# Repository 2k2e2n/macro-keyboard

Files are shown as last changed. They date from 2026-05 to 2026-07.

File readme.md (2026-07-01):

# Macro-Keyboard

完全自作マクロキーボード

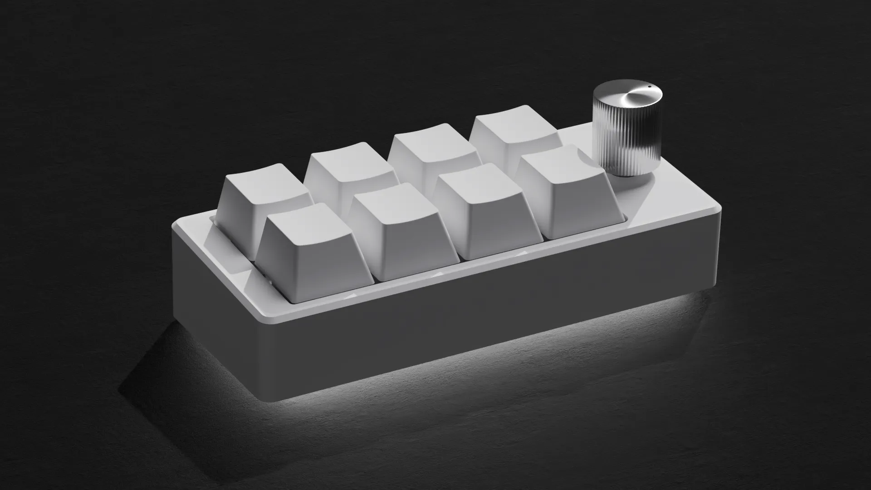
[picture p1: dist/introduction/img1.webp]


---

## Features

* 基板からケースまで完全自作
* webページからキー割り当てを変更可能
* MXcherry hotswapに対応
* ロータリーエンコーダを搭載

## Firmware

[https://2k2e2n.github.io/macro-keyboard/config/](https://2k2e2n.github.io/macro-keyboard/config/)
👆にアクセスして書き換え

もしくは```dist/config/index.html```を開く

## Sales page
作成中

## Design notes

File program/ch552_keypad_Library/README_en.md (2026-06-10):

# ch552_keyPad_Library

Common firmware modules for small keyboards and keypads based on CH552 / ch55xduino.
The folder name for this library is `ch552_keyPad_Library`.
This library includes USB HID composite support (keyboard, mouse, consumer/system, raw HID), watchdog helpers, and NVM keymap handling for programmable devices.

## Usage

Create a folder named `ch552_keyPad_Library` inside Arduino's `libraries` folder, then copy all contents of this repository into it.

## What this library provides

- USB HID composite interface (keyboard, mouse, consumer/system, raw HID channel)
- USB endpoint/setup handling and descriptor constants
- NVM (EEPROM) keymap read/write utilities
- Macro storage and macro index handling in NVM
- Rotary encoder keymap read/write helpers
- CH552 watchdog timer helpers

## Main files

Library files are stored in the `src` directory.

- `USB_hid_composite.c/.h`: HID send API and LED state handling
- `ch_usb_handler.c/.h`: USB endpoint and setup request handling
- `ch_usb_constant.c/.h`: USB descriptors and report constants
- `hid_raw_request.c`: raw HID command handler (for host tools such as WebHID)
- `nvm_keymap.c/.h`: keymap/macro read/write and NVM layout access
- `hardware_config.h`: board/profile dependent memory map and key matrix settings
- `ch552_watchdog.c/.h`: watchdog enable/disable/update helpers
- `hid_keycode.h`: HID keycode definitions

`examples/simple_numPad` contains a simple numpad implementation using this library.

## Build-time configuration

Select one hardware profile in your build flags before including this library:

- `CH552_MACRO_NUMPAD`
- `CH552_MEDIAPAD`

`hardware_config.h` uses these flags to define matrix size, EEPROM map, raw HID ID, and rotary encoder settings.

This library provides a custom CH55x USB handler and therefore requires the CH55xDuino board USB setting that defines `USER_USB_RAM`. If `USER_USB_RAM` is not set, the CH55xDuino core USB handler will conflict with this library and cause duplicate symbol errors.

When adding new hardware support that uses this library, define an appropriate preprocessor macro as needed and update files in this library accordingly. Then specify that macro in `arduino.json` on the hardware implementation side.

Note: if you are not using an NVM-based keymap, as in `examples/simple_numPad`, no build flags are needed.

## Public APIs (high level)

- Watchdog: `wdt_enable()`, `wdt_disable()`, `wdt_update()`
- NVM keymap: `init_nvm_keymap()`, `read_nvm_code()`, `write_nvm_code()`
- Bulk keymap/macro access: `read_keys()`, `write_keys()`, `read_macros()`, `write_macros()`
- USB HID: `usbhid_init()`, `send_key()`, `send_modifiers()`, `kbd_releaseAll()`, `get_hid_ledstate()`

## Raw HID command notes

`hid_raw_request.c` implements command IDs for:

- keymap reset/read/write
- macro read/write
- rotary encoder key read/write
- version query
- bootloader entry

Use this interface from a host configurator to update keymaps and macros stored in NVM.

## License

Copyright (c) 2024 Takeshi Higasa, okiraku-camera.tokyo

MIT License.

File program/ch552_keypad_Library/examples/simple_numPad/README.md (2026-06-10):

# Simple Numeric Keypad Firmware for CH552G

This directory provides a **simple numeric keypad firmware** for the **CH552G** microcontroller. The firmware is intended primarily for **hardware bring-up and USB HID verification**. It enumerates as a **standard USB HID keyboard** and sends key events by scanning 4x5 key-switch matrix. This implementation is based on the `USBHIDKeyboard.c` example included in **CH55xDuino**.

`simple_numPad.ino` uses the **ch552_keyPad_Library** and is provided as one of the examples included with that library. The library supplies the shared CH552 keypad firmware modules, including USB HID handling, watchdog helpers, and keymap/NVM support used by this example.

---

## Features

- Minimal **USB HID keyboard implementation**
- Designed for **CH552G hardware bring-up**
- Simple **Matrix-based numeric keypad**
- Based on the **CH55xDuino USBHIDKeyboard example**
- Easy to build with **Arduino IDE or VS Code**

---

## Build Environment

The firmware can be built using:

- **Arduino IDE 1.8.19**
- **Visual Studio Code** with the *vscode-arduino* extension

Both require **CH55xDuino v0.25**.

### Board Configuration

In the board configuration menu, select:

- **USB Settings:** `USER CODE w/ 148B USB ram`

This option allocates the USB RAM required for HID endpoints.

---

## Hardware

This firmware targets the **ch552_numPad_rev2** hardware. The circuit designs and related files are maintained in a separate repository (**ch552_numPad_rev2**), which is independent of this library repository.

---

## License

Copyright (c) 2023 Takeshi Higasa, okiraku-camera.tokyo
Released under the **MIT License**.

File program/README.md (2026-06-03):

# Macro Keyboard (CH55x)

このディレクトリには、CH55x（CH552/CH554）を使った簡易ショートカットキーボードのファームウェアと設定ツールがあります。

内容:
- `firmware/MacroKeyboard.ino` - Arduino IDE（ch55xduinoコア）用スケッチ
- `configurator/index.html` - ブラウザで編集・ダウンロード・Web Serialでアップロード可能な設定ページ
- `uploader/serial_uploader.py` - シリアル経由で設定を送る簡易Pythonスクリプト

使い方（概要）:
1. Arduino IDEに`ch55xduino`コアをインストールして、`firmware/MacroKeyboard/MacroKeyboard.ino`を開く
2. **ツール > USB Settings** で **「USER CODE w/ 266B USB ram」** を選択（CDC + HID キーボード/マウス用）
3. 指定のピン割り当てを確認してビルド・書き込み
4. 設定を変更するには、`configurator/index.html`を開いてキーを編集後「Download」または「Connect & Upload」を使う
   - Web Serialが使えない場合はダウンロードした`keymap.txt`を`uploader/serial_uploader.py`で送信

設定フォーマット:
- デバイスは起動時に`P3.0`（debug）を押しながら電源投入/リセットすると、115200bpsでシリアルを開いて8個のトークンをカンマ区切りで受け取ります。
- 例: `a,CTRL+B,ENTER,MW_UP,WIN, ,LEFT,SPACE`
- トークンは単一文字、修飾キーとの組み合わせ（`CTRL+A`）、特殊キー名（`ENTER`,`TAB`,`LEFT`など）、およびマウスホイール (`MW_UP`/`MW_DOWN`) をサポートします。

注記:
- 永続化（フラッシュへの保存）や高度なキーコード（ファンクションキー、修飾キー）は簡易化のため未実装です。必要なら次のステップで追加します。

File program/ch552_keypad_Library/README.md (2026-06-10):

# ch552_keyPad_Library

English version is here: [README_en.md](README_en.md)

CH552 / ch55xduino ベースの小型キーボード・キーパッド向け共通ファームウェアモジュールです。
このフォルダ名は `ch552_keyPad_Library` です。
本ライブラリは、USB HIDコンポジット対応（keyboard, mouse, consumer/system, raw HID）、ウォッチドッグ補助、NVMキーマップを提供します。

## 使い方

Arduino の `libraries` フォルダ内に `ch552_keyPad_Library` というフォルダを作成し、このリポジトリ内容をすべてコピーしてください。

## このライブラリが提供する機能

- USB HIDコンポジットインターフェース（keyboard, mouse, consumer/system, raw HIDチャネル）
- USBエンドポイント/SETUP処理とディスクリプタ定数
- NVM（EEPROM）キーマップの読み書きユーティリティ
- NVM内のマクロ保存とマクロインデックス処理
- ロータリーエンコーダ用キーマップ読み書き補助
- CH552ウォッチドッグタイマ補助

## 主なファイル

ライブラリファイルは `src` ディレクトリに格納しています。

- `USB_hid_composite.c/.h`: HID送信APIとLED状態処理
- `ch_usb_handler.c/.h`: USBエンドポイントとSETUPリクエスト処理
- `ch_usb_constant.c/.h`: USBディスクリプタとレポート定数
- `hid_raw_request.c`: raw HIDコマンドハンドラ（WebHIDなどのホストツール向け）
- `nvm_keymap.c/.h`: キーマップ/マクロの読み書きとNVMレイアウトアクセス
- `hardware_config.h`: ボード/プロファイル依存のメモリマップとキーマトリクス設定
- `ch552_watchdog.c/.h`: ウォッチドッグの有効化/無効化/更新ヘルパー
- `hid_keycode.h`: HIDキーコード定義

`examples/simple_numPad` に、このライブラリを使ったシンプルなテンキーの実装例があります。

## ビルド時設定

現在のライブラリ構成では、以下の2つのビルドフラグによって対象ハードウェアを選択します。

- `CH552_MACRO_NUMPAD`
- `CH552_MEDIAPAD`

また、CH55xDuino コアの標準 USB ハンドラとこのライブラリの USB ハンドラが衝突するため、CH55xDuino のボード USB 設定で `USER_USB_RAM` が定義されているモードを選択してください。通常はボードの USB 設定メニューで `user0` / `user148` などのユーザー USB RAM モードを使います。

`hardware_config.h` はこれらのフラグを使って、マトリクスサイズ、EEPROMマップ、raw HID ID、ロータリーエンコーダ設定を定義します。

このライブラリを使うハードウェアを追加するときには、必要に応じて適切なプリプロセッサマクロを定義し、ライブラリ内のファイルを更新します。そしてハードウェア実装側の arduino.json 内にそのマクロを指定します。

なお、`examples/simple_numPad` のように、NVM上のキーマップを利用しない場合、フラグは不要です。

## 公開API（概要）

- Watchdog: `wdt_enable()`, `wdt_disable()`, `wdt_update()`
- NVM keymap: `init_nvm_keymap()`, `read_nvm_code()`, `write_nvm_code()`
- Bulk keymap/macro access: `read_keys()`, `write_keys()`, `read_macros()`, `write_macros()`
- USB HID: `usbhid_init()`, `send_key()`, `send_modifiers()`, `kbd_releaseAll()`, `get_hid_ledstate()`

## Raw HIDコマンド

`hid_raw_request.c` は次のコマンドIDを実装しています。

- keymapのリセット/読み出し/書き込み
- macroの読み出し/書き込み
- rotary encoder keyの読み出し/書き込み
- バージョン問い合わせ
- ブートローダ起動

このインターフェースを使うことで、ホスト側コンフィギュレータからNVM上のキーマップとマクロを更新できます。

## License

Copyright (c) 2024 Takeshi Higasa, okiraku-camera.tokyo

MIT License.

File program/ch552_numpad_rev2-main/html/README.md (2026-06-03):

# macro_numpad WebUI 使い方ガイド

English version is here: [README_en.md](README_en.md)

## 概要

このドキュメントでは、`macro_numpad.html` を使ってキーボード本体のキーマップ・マクロを設定する手順を説明します。
`macro_numpad.js` がWebHID通信と画面制御を担当し、`style.css` がUIの見た目を担当します。

## 動作要件

- WebHID対応ブラウザ（Chrome / Edge 推奨）
- USB接続された macro_numpad デバイス
- この `html` ディレクトリ内ファイル一式

## 起動方法

1. `macro_numpad.html` をブラウザで開きます。
2. 画面上部の「キーボードに接続」を押します。
3. デバイス選択ダイアログで対象デバイスを選びます。
4. 接続に成功すると、キーマップとマクロが自動読み出しされます。

## 画面構成

- 接続ボタン: WebHIDでデバイス接続を開始します。
- キーマップ操作ボタン:
  - キーマップを読み出す
  - キーマップを書き込む
  - マクロを読み出す
  - マクロを書き込む
- マクロ編集ボタン: マクロエディタを開きます。
- テンキー表示領域: キーの現在割り当てと変更状態を表示します。
- 補助ボタン:
  - デフォルトにリセット
  - ブートローダー開始
  - NVMを読み出す
  - macro ptrs
- ログ領域: 操作結果、通信エラー、デバッグ情報を表示します。

## キーマップ設定の流れ

1. 変更したいキーをテンキー表示領域でクリックします。
2. キー選択ダイアログからキーを選びます。
3. 必要なら修飾キー（Shift/Ctrl/Alt/Win）を有効にします。
4. 設定後、キーに保留マーク（⏳）が表示されます。
5. 「キーマップを書き込む」を押してデバイスへ反映します。

### スイッチ0の設定

- スイッチ0は通常キーではなくモード制御用です。
- 特殊ダイアログで以下を選びます。
  - Num: テンキーモード
  - Fn: マクロパッドモード（レイヤー切替）

## マクロ設定の流れ

1. 「マクロを編集する」を押してマクロエディタを開きます。
2. 編集対象のスロット（m0〜m5）を選択します。
3. キー群からコードを順番に追加します。
4. 必要に応じて遅延コード（100ms/500ms/1sec）を追加します。
5. 間違えた場合は「最後を削除」または「クリア」で修正します。
6. 「マクロを書き込む」を押してデバイスに保存します。

### マクロ割り当て

1. 通常のキー設定ダイアログで割り当て対象キーを選びます。
2. マクロトリガー（m0〜m5）を選択します。
3. 「キーマップを書き込む」で保存します。

### 実行中断

マクロ送信中にいずれかのキーを押すと、送信中のマクロは停止します。

## NVM関連操作

- キーマップを読み出す: デバイスNVMのキー設定を読み込みます。
- マクロを読み出す: デバイスNVMのマクロデータを読み込みます。
- NVMを読み出す: 生データを16進表示します（デバッグ用途）。
- macro ptrs: マクロ先頭ポインタ情報を表示します（デバッグ用途）。
- デフォルトにリセット: キーマップ初期状態とマクロ消去を行います。

## 重要な注意点

- 接続中デバイスが抜線・リセットされた場合、操作は無効になります。再接続してください。
- キーマップ変更とマクロ変更は別保存です。必要に応じて両方書き込んでください。
- ブートローダー開始を実行すると、デバイスが一時的に切断されることがあります。

## トラブルシューティング

### デバイスが表示されない

- USBケーブルのデータ通信対応を確認してください。
- ブラウザのWebHID対応状況を確認してください。
- 他アプリが同じデバイスを占有していないか確認してください。

### 書き込みできない

- 先に接続が成功しているか確認してください。
- ログ欄のエラー（Timeout、Version mismatch など）を確認してください。
- 一度「キーマップを読み出す」後に再編集して再実行してください。

### マクロが期待どおり動かない

- マクロスロットの中身と割り当て先キーを再確認してください。
- 遅延コードの入れすぎで体感上遅くなっていないか確認してください。
- マクロ容量上限（45バイト）を超えていないか確認してください。

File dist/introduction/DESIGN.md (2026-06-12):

---
name: Monolith Aesthetic
colors:
  surface: '#141313'
  surface-dim: '#141313'
  surface-bright: '#3a3939'
  surface-container-lowest: '#0e0e0e'
  surface-container-low: '#1c1b1b'
  surface-container: '#201f1f'
  surface-container-high: '#2a2a2a'
  surface-container-highest: '#353434'
  on-surface: '#e5e2e1'
  on-surface-variant: '#c5c7c9'
  inverse-surface: '#e5e2e1'
  inverse-on-surface: '#313030'
  outline: '#8f9194'
  outline-variant: '#44474a'
  surface-tint: '#c6c6c8'
  primary: '#ffffff'
  on-primary: '#2f3132'
  primary-container: '#e2e2e4'
  on-primary-container: '#636466'
  inverse-primary: '#5d5e60'
  secondary: '#c6c6c6'
  on-secondary: '#303030'
  secondary-container: '#474747'
  on-secondary-container: '#b5b5b5'
  tertiary: '#ffffff'
  on-tertiary: '#2f3034'
  tertiary-container: '#e3e2e7'
  on-tertiary-container: '#646469'
  error: '#ffb4ab'
  on-error: '#690005'
  error-container: '#93000a'
  on-error-container: '#ffdad6'
  primary-fixed: '#e2e2e4'
  primary-fixed-dim: '#c6c6c8'
  on-primary-fixed: '#1a1c1d'
  on-primary-fixed-variant: '#454749'
  secondary-fixed: '#e2e2e2'
  secondary-fixed-dim: '#c6c6c6'
  on-secondary-fixed: '#1b1b1b'
  on-secondary-fixed-variant: '#474747'
  tertiary-fixed: '#e3e2e7'
  tertiary-fixed-dim: '#c7c6cb'
  on-tertiary-fixed: '#1a1b1f'
  on-tertiary-fixed-variant: '#46464b'
  background: '#141313'
  on-background: '#e5e2e1'
  surface-variant: '#353434'
typography:
  display-lg:
    fontFamily: Hanken Grotesk
    fontSize: 72px
    fontWeight: '700'
    lineHeight: 80px
    letterSpacing: -0.02em
  display-lg-mobile:
    fontFamily: Hanken Grotesk
    fontSize: 40px
    fontWeight: '700'
    lineHeight: 44px
    letterSpacing: -0.01em
  headline-md:
    fontFamily: Hanken Grotesk
    fontSize: 32px
    fontWeight: '600'
    lineHeight: 40px
    letterSpacing: -0.01em
  body-lg:
    fontFamily: Inter
    fontSize: 18px
    fontWeight: '400'
    lineHeight: 28px
    letterSpacing: '0'
  body-md:
    fontFamily: Inter
    fontSize: 16px
    fontWeight: '400'
    lineHeight: 24px
    letterSpacing: '0'
  label-caps:
    fontFamily: Geist
    fontSize: 12px
    fontWeight: '600'
    lineHeight: 16px
    letterSpacing: 0.1em
  mono-technical:
    fontFamily: Geist
    fontSize: 14px
    fontWeight: '400'
    lineHeight: 20px
    letterSpacing: '0'
rounded:
  sm: 0.25rem
  DEFAULT: 0.5rem
  md: 0.75rem
  lg: 1rem
  xl: 1.5rem
  full: 9999px
spacing:
  unit: 8px
  container-max: 1440px
  gutter: 32px
  margin-desktop: 80px
  margin-mobile: 24px
  section-gap: 160px
---

## Brand & Style

This design system is built for the intersection of precision engineering and high-end lifestyle. It targets enthusiasts who view mechanical keyboards not just as tools, but as bespoke pieces of industrial art. The brand personality is quiet, confident, and authoritative, favoring "less but better."

The visual style is **Minimalist with Glassmorphic accents**. It draws heavily from modern industrial design, utilizing vast expanses of negative space to frame high-fidelity product photography. The emotional response should be one of "calm technicality"—evoking the tactile click of a well-machined switch and the premium weight of an aluminum chassis.

## Colors

The palette is strictly monochromatic with a singular functional accent. 
- **Primary (#F5F5F7):** Used for typography on dark backgrounds and high-signal elements.
- **Secondary (#000000):** The foundation. Deep blacks create an infinite canvas for product shots.
- **Tertiary (#86868B):** Used for secondary metadata and disabled states to maintain low visual noise.
- **Accent (#007AFF):** A precise, high-chroma blue used sparingly for interactive states (links, active toggles).

The default state is **Dark Mode**. Light mode should only be used for physical documentation or high-contrast editorial spreads. Use `#1D1D1F` for elevated surfaces to maintain depth against the pure black background.

## Typography

The typographic hierarchy prioritizes legibility and a "technical-luxe" feel.
- **Headlines:** Use **Hanken Grotesk** for its sharp, contemporary geometry. Tighten tracking on large displays to create a solid, impactful block of text.
- **Body:** **Inter** provides a neutral, utilitarian balance that ensures long-form specifications are easy to digest.
- **Technical Labels:** **Geist** is used for monospaced data points (e.g., actuation force, weight, polling rate), reinforcing the developer-centric and engineering-heavy nature of the product.

Generous letter spacing is applied specifically to `label-caps` to evoke the high-end feel of luxury watch branding.

## Layout & Spacing

This design system uses a **Fixed Grid** model for desktop and a **Fluid Grid** for mobile. 
- **Desktop:** A 12-column grid with a 1440px max-width. Sections are separated by "massive whitespace" (160px gaps) to force focus on one component or feature at a time.
- **Mobile:** A 4-column grid with 24px side margins. 

The spacing rhythm is strictly based on an 8px base unit. Margin and padding should always be multiples of 8. Elements should feel "airy"—never crowd a product image with text. If a component feels cramped, double the padding.

## Elevation & Depth

Depth is achieved through **Tonal Layering** and **Glassmorphism**, rather than traditional heavy shadows.
- **Level 0 (Background):** Pure `#000000`.
- **Level 1 (Cards/Containers):** `#1D1D1F` with a subtle 1px border of `#F5F5F7` at 10% opacity.
- **Level 2 (Overlays/Modals):** Glassmorphism. Use a background blur of 20px-40px with a white fill at 5-10% opacity. This simulates the frosted look of polycarbonate keyboard cases.
- **Shadows:** Only used to separate Level 2 elements from Level 1. Use a highly diffused, 0% offset shadow: `0 20px 40px rgba(0,0,0,0.5)`.

## Shapes

The shape language reflects the "squircle" geometry found in premium industrial design. 
- **Standard UI elements** (Inputs, Buttons) use a **0.5rem (8px)** radius.
- **Feature Cards and Images** use a much more aggressive **1.5rem (24px)** radius (`rounded-xl`) to mimic the rounded corners of a keyboard chassis.
- Buttons should never be fully pill-shaped; they must maintain a structured, rectangular essence with soft corners to feel like physical keycaps.

## Components

- **Buttons:** Primary buttons are Solid `#F5F5F7` with `#000000` text. Secondary buttons are "Ghost" style: 1px border of `#86868B` with no fill.
- **Chips:** Small, technical indicators using `label-caps` typography. They use a dark gray background (`#2C2C2E`) to stay unobtrusive.
- **Inputs:** Dark fields with a 1px bottom border only. On focus, the border transitions to the Accent Blue. Use `mono-technical` for input text.
- **Cards:** Utilize the glassmorphism rules from Section 5. Cards should have generous internal padding (min 40px) and use high-resolution, low-key lighting imagery.
- **Interactive States:** Use "Spring" physics for all hover interactions. A slight scale-up (1.02x) on cards and buttons provides a tactile, physical response.
- **Spec List:** A vertical list where the label is `label-caps` in `#86868B` and the value is `body-lg` in `#F5F5F7`.

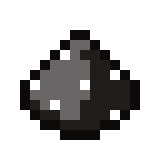
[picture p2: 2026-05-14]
case/Top-mount/img/Redstonedust_grey.png

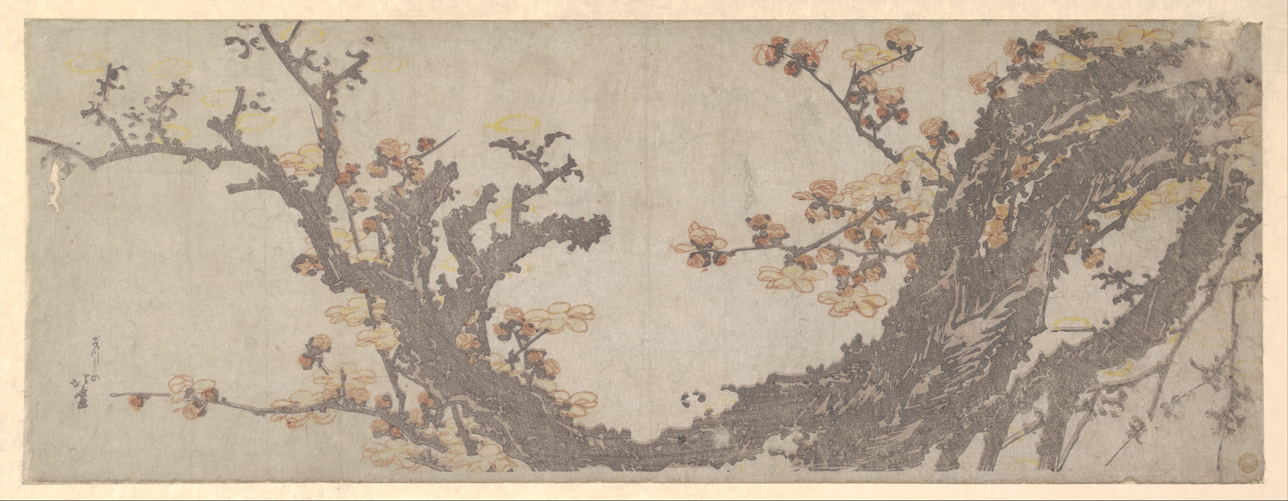
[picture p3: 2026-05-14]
case/Top-mount/img/DP146854.jpg

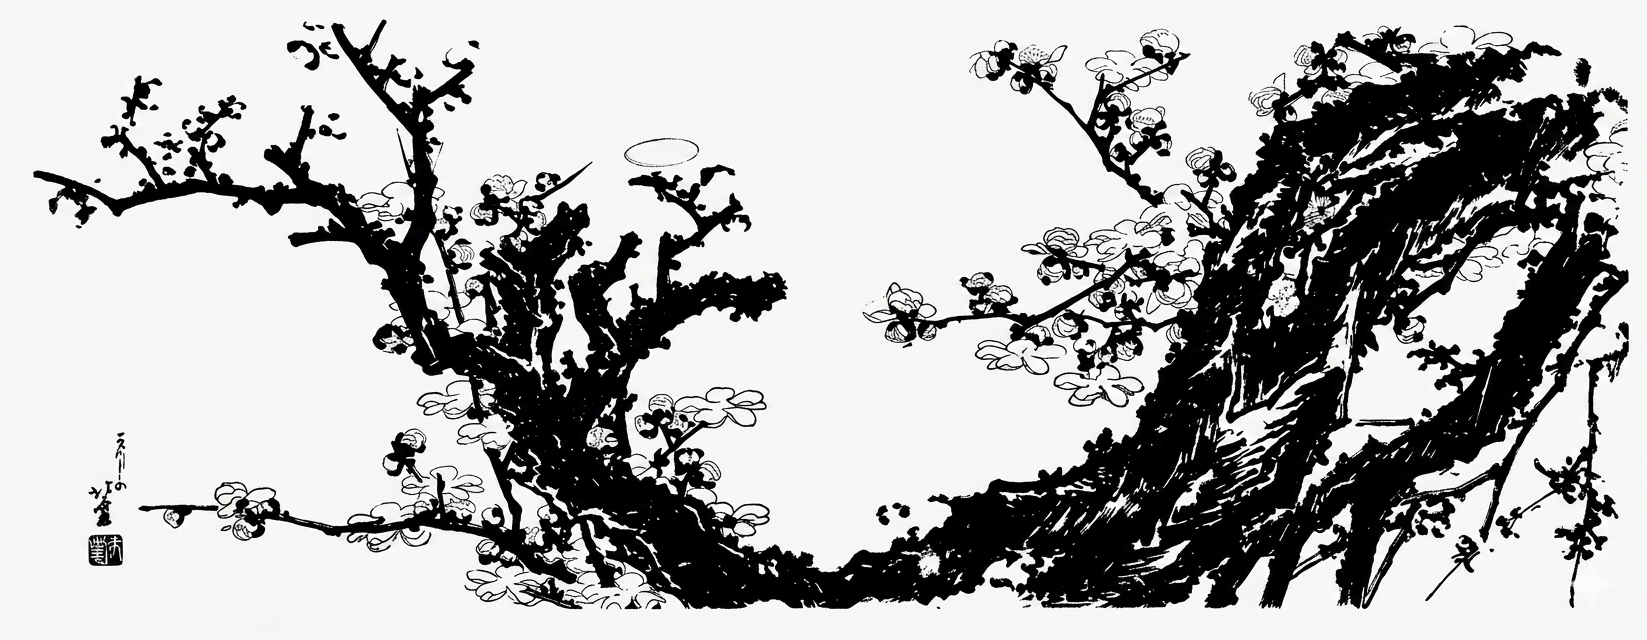
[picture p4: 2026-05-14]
case/Top-mount/img/Gemini_Generated_Image_gcpa9igcpa9igcpa.png

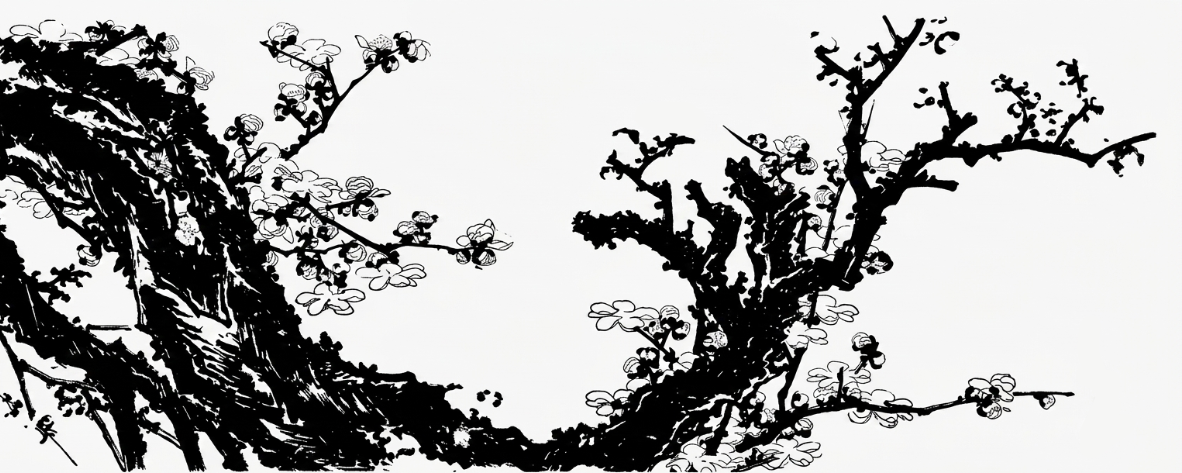
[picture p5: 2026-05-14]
case/Top-mount/img/名称未設定.png

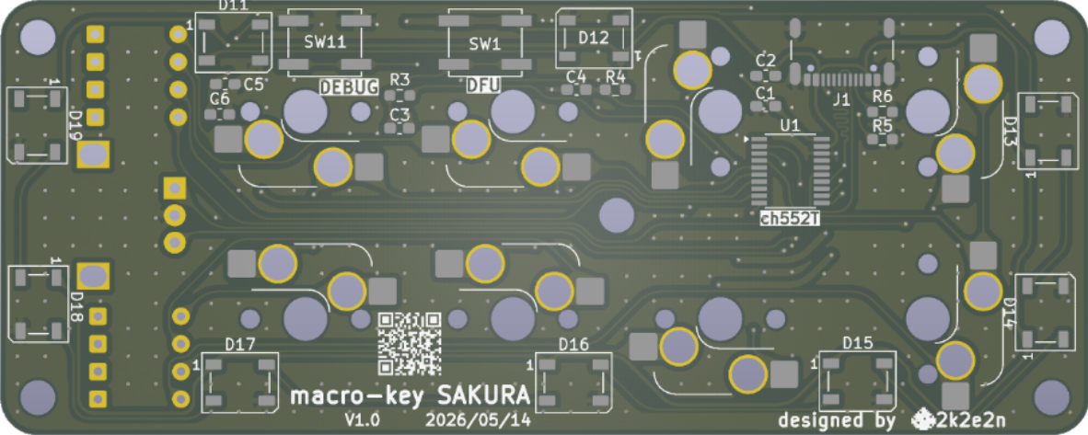
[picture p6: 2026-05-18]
case/macro-keyboard-silk-bottom.png

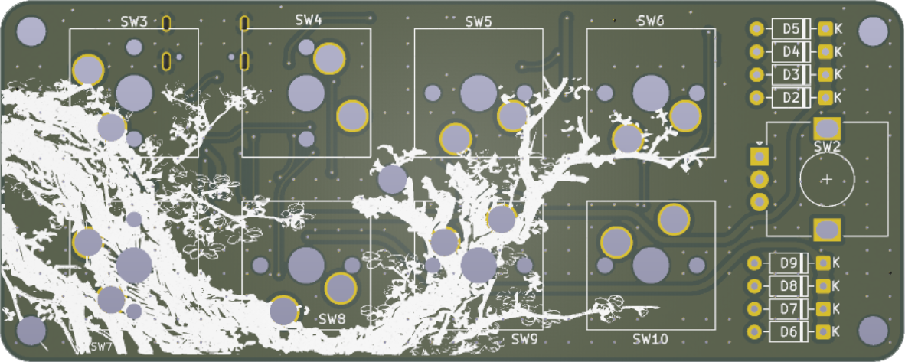
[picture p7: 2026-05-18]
case/macro-keyboard-silk-top.png

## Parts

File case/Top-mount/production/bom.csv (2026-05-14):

Designator | Footprint | Quantity | Value | LCSC Part #
C1, C2, C3, C4, C5 | 0603 | 5 | 0.1u
C6 | 0603 | 1 | 3.9u
D11, D12, D13, D14, D15, D16, D17, D18, D19 | LED_WS2812B_PLCC4_5.0x5.0mm_P3.2mm | 9 | WS2812B
D2, D3, D4, D5, D6, D7, D8, D9 | D_DO-35_SOD27_P7.62mm_Horizontal | 8 | D
J1 | USB_C_Receptacle_GCT_USB4105-xx-A_16P_TopMnt_Horizontal | 1 | USB_C_Receptacle_USB2.0_16P
R3, R4 | 0603 | 2 | 10k
R5, R6 | 0603 | 2 | 5.1k
SW1, SW11 | SW_SPST_EVQP0 | 2 | DFU-mode
SW10, SW3, SW4, SW5, SW6, SW7, SW8, SW9 | SW_Hotswap_Kailh_MX_Plated_1.00u | 8 | keySW
SW2 | RotaryEncoder_Alps_EC12E_Vertical_H20mm | 1 | RotaryEncoder
U1 | TSSOP-20_4.4x6.5mm_P0.65mm | 1 | CH552T

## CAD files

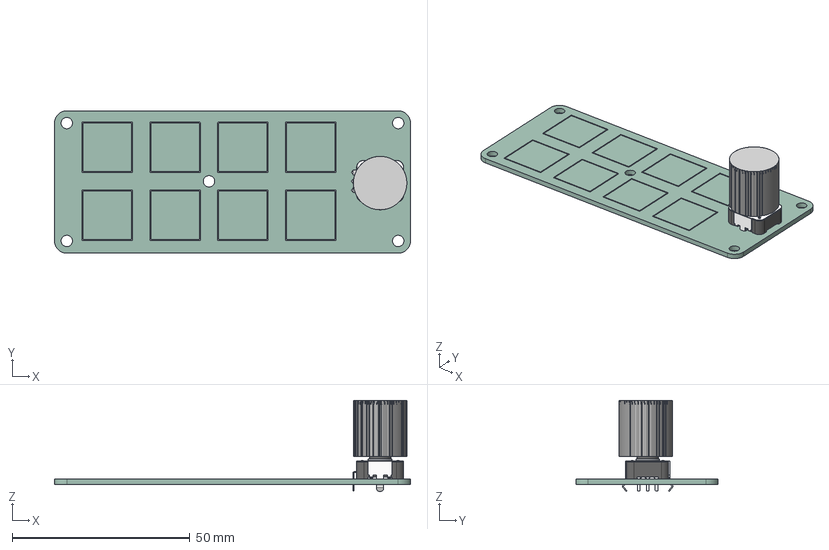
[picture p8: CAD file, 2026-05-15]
case/Top-mount/topmount.step
100.0 x 40.0 x 25.6 mm
EC12 Encoder 10mm 3pin
ãã
macro-keyboard-case_PCB

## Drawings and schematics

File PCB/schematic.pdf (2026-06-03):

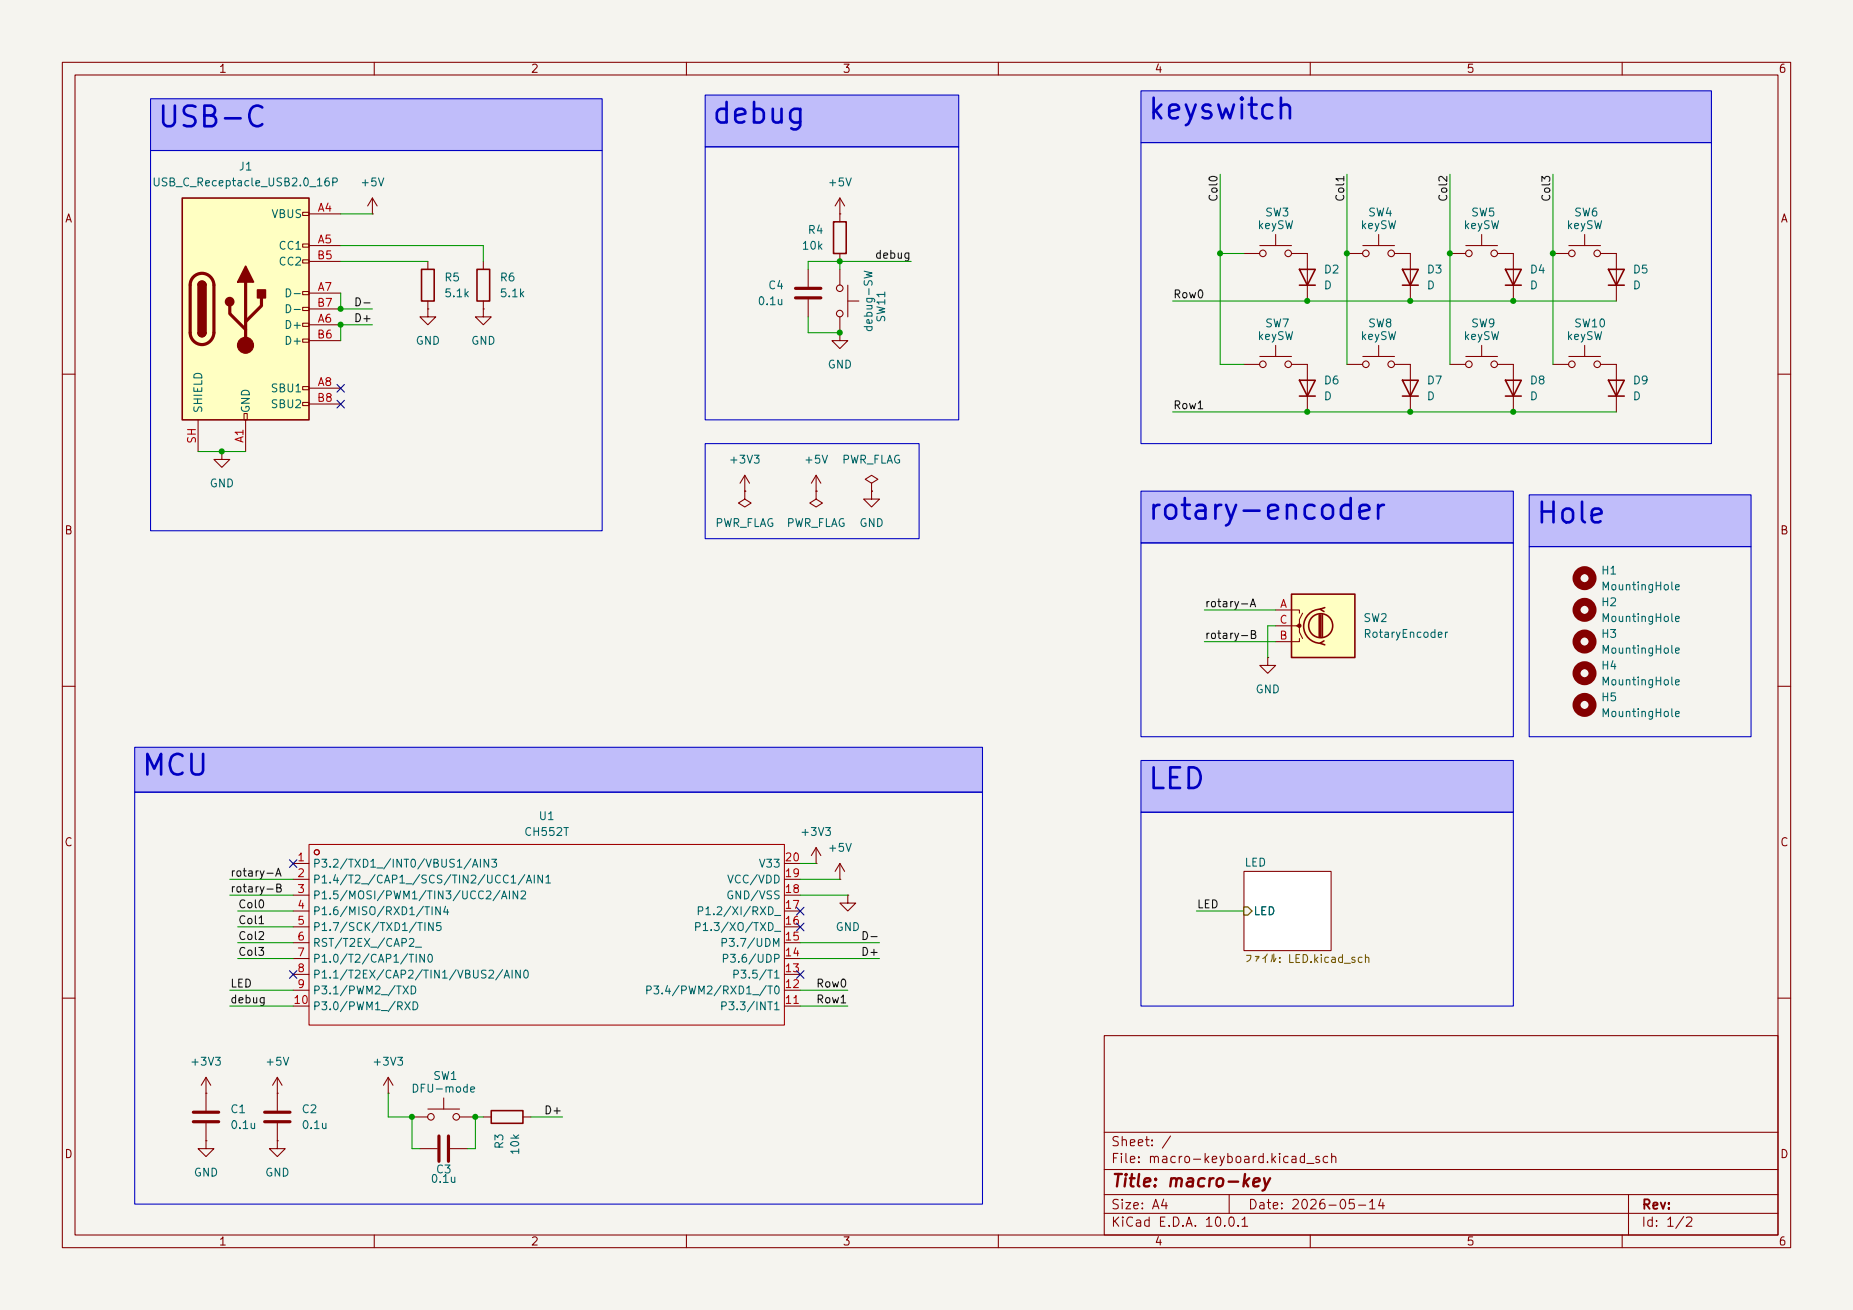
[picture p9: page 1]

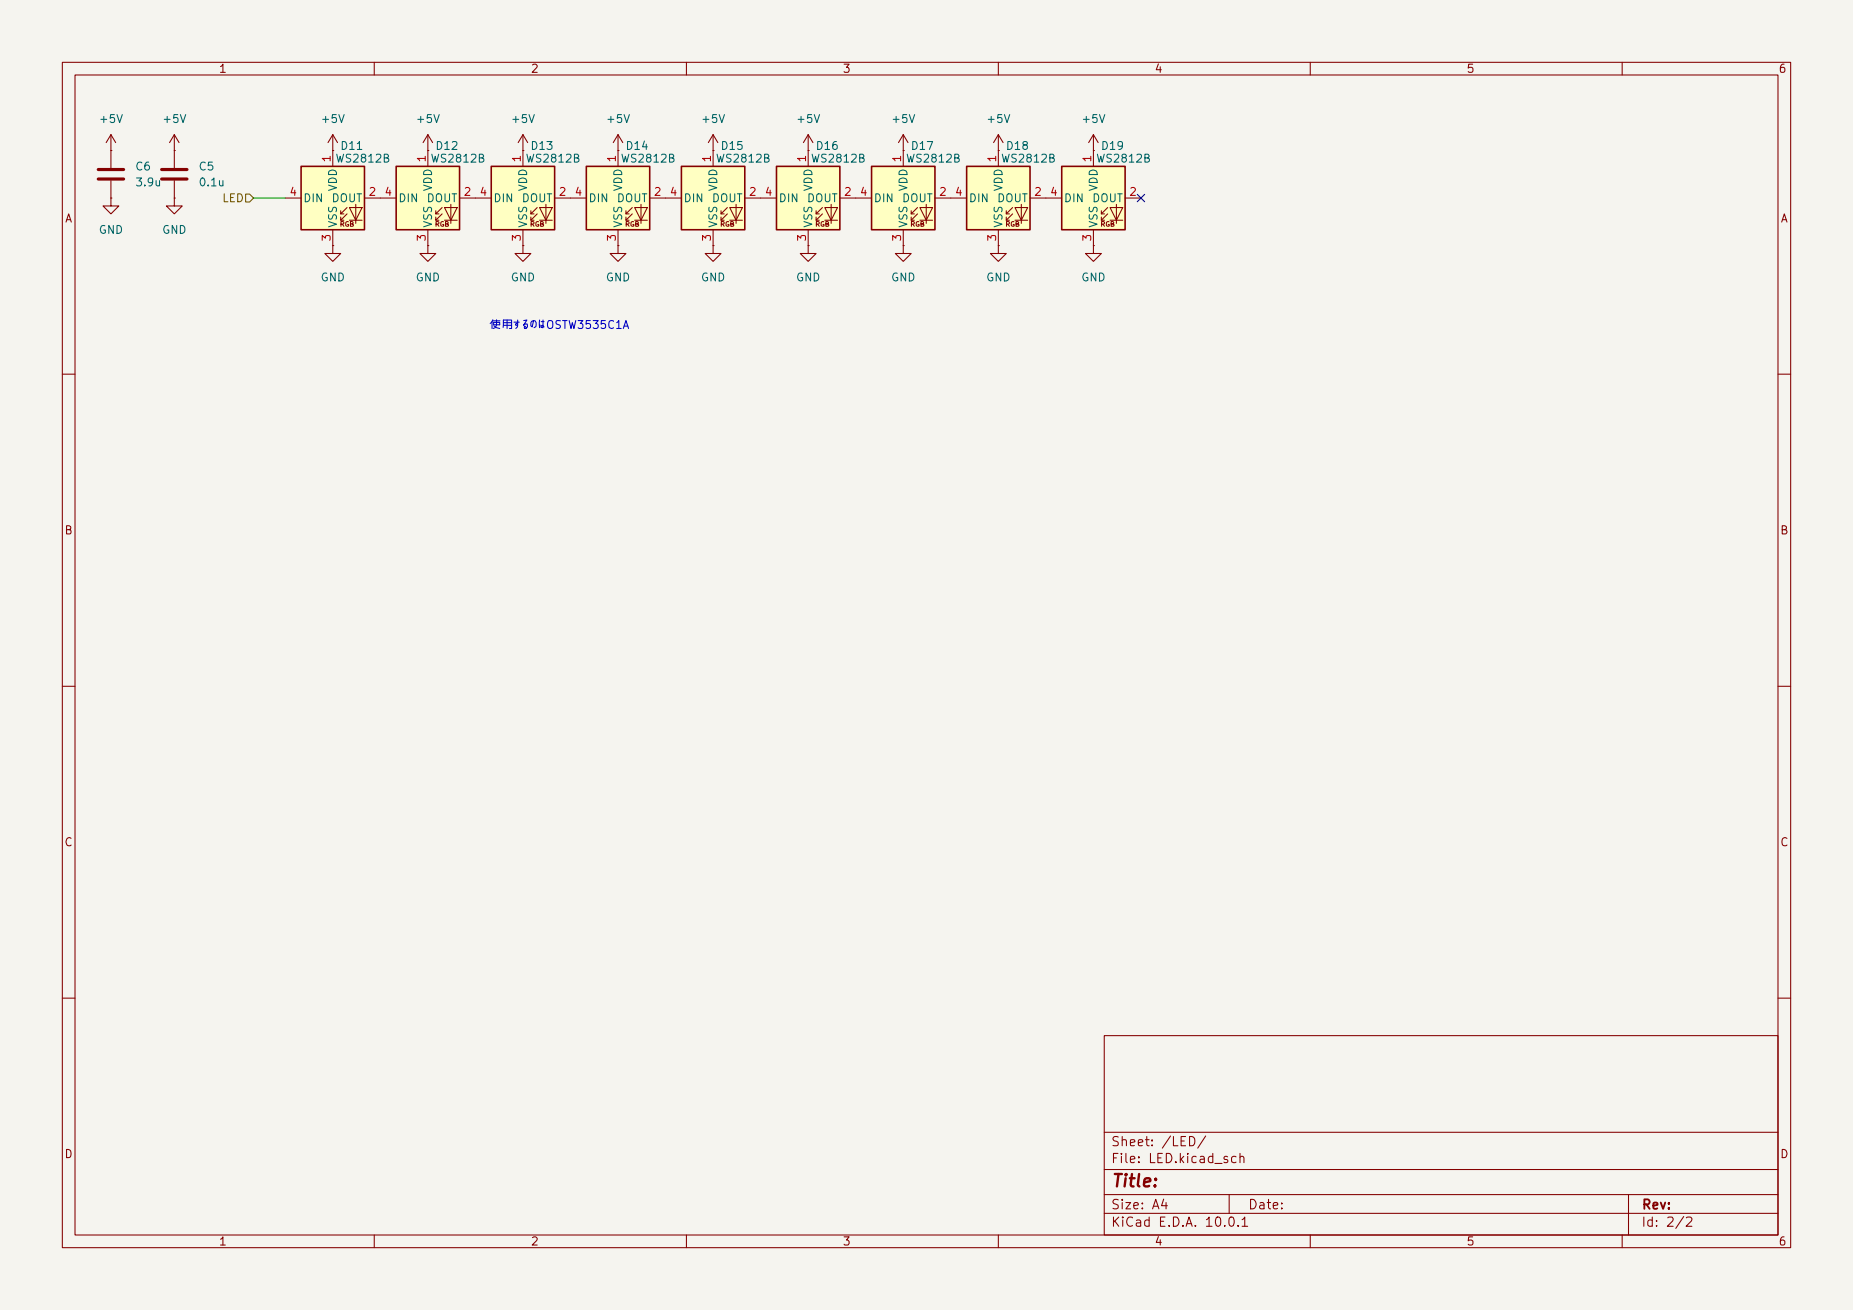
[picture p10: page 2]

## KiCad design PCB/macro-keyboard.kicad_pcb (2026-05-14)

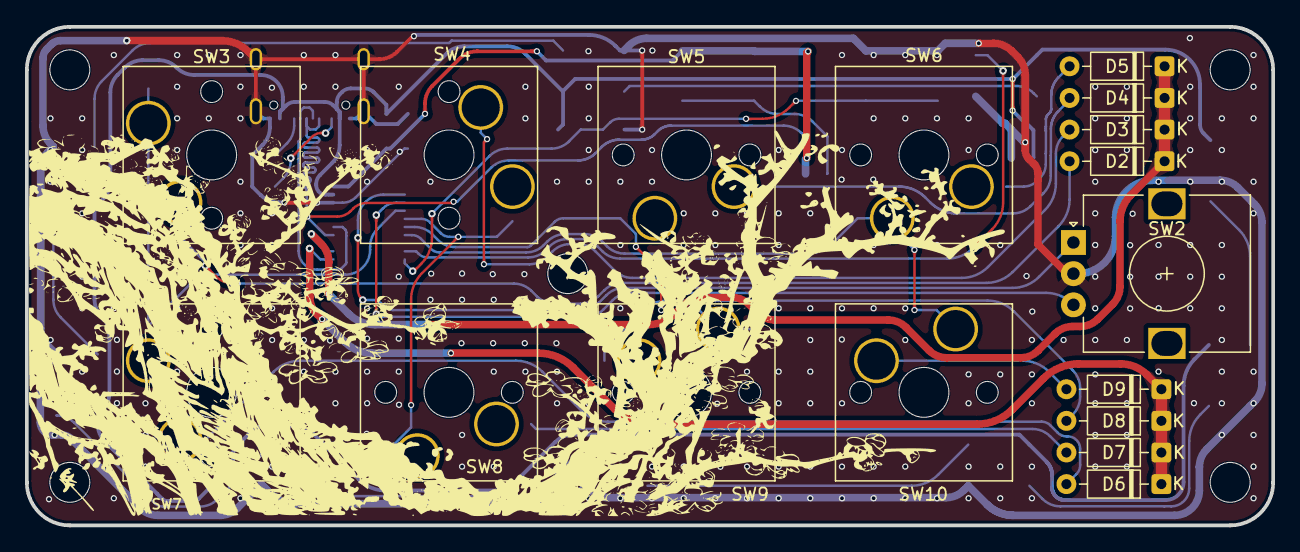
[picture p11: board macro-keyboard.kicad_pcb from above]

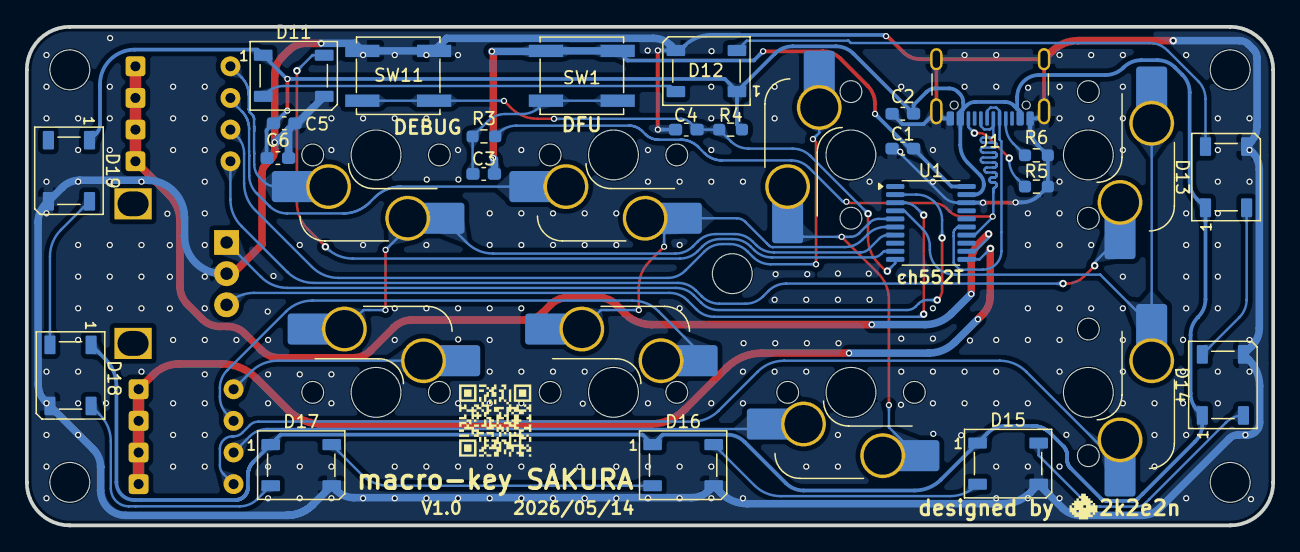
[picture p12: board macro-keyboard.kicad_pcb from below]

Board: 2 copper layers, 100.0 x 40.0 mm, 46 parts (24 on the bottom side), 34 nets.

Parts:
C1, C2, C3, C4, C5: 0.1u; C_0603_1608Metric_Pad1.08x0.95mm_HandSolder
C6: 3.9u; C_0603_1608Metric_Pad1.08x0.95mm_HandSolder
D2, D3, D4, D5, D6, D7, D8, D9: D; D_DO-35_SOD27_P7.62mm_Horizontal
D11, D12, D13, D14, D15, D16, D17, D18, D19: WS2812B; LED_WS2812B_PLCC4_5.0x5.0mm_P3.2mm
H1, H2, H3, H4, H5: MountingHole; MountingHole_3.2mm_M3
J1: USB_C_Receptacle_USB2.0_16P; USB_C_Receptacle_GCT_USB4105-xx-A_16P_TopMnt_Horizontal
QR*****: qrcode
R3, R4: 10k; R_0603_1608Metric_Pad0.98x0.95mm_HandSolder
R5, R6: 5.1k; R_0603_1608Metric_Pad0.98x0.95mm_HandSolder
SW1, SW11: DFU-mode; SW_SPST_EVQP0
SW2: RotaryEncoder; RotaryEncoder_Alps_EC12E_Vertical_H20mm
SW3, SW4, SW5, SW6, SW7, SW8, SW9, SW10: keySW; SW_Hotswap_Kailh_MX_Plated_1.00u
U1: CH552T; TSSOP-20_4.4x6.5mm_P0.65mm

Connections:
+3V3: C1.1, C3.1, SW1.2, U1.20 (V33)
+5V: C2.1, C5.1, C6.1, D11.1 (VDD), D12.1 (VDD), D13.1 (VDD), D14.1 (VDD), D15.1 (VDD), D16.1 (VDD), D17.1 (VDD), D18.1 (VDD), D19.1 (VDD), J1.A4 (VBUS), J1.A9 (VBUS), J1.B4 (VBUS), J1.B9 (VBUS), R4.2, U1.19 (VCC/VDD)
/Col0: SW3.2, SW7.2, U1.4 (P1.6/MISO/RXD1/TIN4)
/Col1: SW4.2, SW8.2, U1.5 (P1.7/SCK/TXD1/TIN5)
/Col2: SW5.2, SW9.2, U1.6 (RST/T2EX_/CAP2_)
/Col3: SW6.2, SW10.2, U1.7 (P1.0/T2/CAP1/TIN0)
/D+: J1.A6 (D+), J1.B6 (D+), R3.2, U1.14 (P3.6/UDP)
/D-: J1.A7 (D-), J1.B7 (D-), U1.15 (P3.7/UDM)
/LED: D11.4 (DIN), U1.9 (P3.1/PWM2_/TXD)
/Row0: D2.1 (K), D3.1 (K), D4.1 (K), D5.1 (K), U1.12 (P3.4/PWM2/RXD1_/T0)
/Row1: D6.1 (K), D7.1 (K), D8.1 (K), D9.1 (K), U1.11 (P3.3/INT1)
/debug: C4.2, R4.1, SW11.2, U1.10 (P3.0/PWM1_/RXD)
/rotary-A: SW2.A, U1.2 (P1.4/T2_/CAP1_/SCS/TIN2/UCC1/AIN1)
/rotary-B: SW2.B, U1.3 (P1.5/MOSI/PWM1/TIN3/UCC2/AIN2)
GND: C1.2, C2.2, C4.1, C5.2, C6.2, D11.3 (VSS), D12.3 (VSS), D13.3 (VSS), D14.3 (VSS), D15.3 (VSS), D16.3 (VSS), D17.3 (VSS), D18.3 (VSS), D19.3 (VSS), J1.A1 (GND), J1.A12 (GND), J1.B1 (GND), J1.B12 (GND), J1.SH (SHIELD), R5.2, R6.2, SW2.C, SW11.1, U1.18 (GND/VSS)
unnamed: C3.2, R3.1, SW1.1
unnamed: D2.2 (A), SW3.1
unnamed: D3.2 (A), SW4.1
unnamed: D4.2 (A), SW5.1
unnamed: D5.2 (A), SW6.1
unnamed: D6.2 (A), SW7.1
unnamed: D7.2 (A), SW8.1
unnamed: D8.2 (A), SW9.1
unnamed: D9.2 (A), SW10.1
unnamed: D11.2 (DOUT), D12.4 (DIN)
unnamed: D12.2 (DOUT), D13.4 (DIN)
unnamed: D13.2 (DOUT), D14.4 (DIN)
unnamed: D14.2 (DOUT), D15.4 (DIN)
unnamed: D15.2 (DOUT), D16.4 (DIN)
unnamed: D16.2 (DOUT), D17.4 (DIN)
unnamed: D17.2 (DOUT), D18.4 (DIN)
unnamed: D18.2 (DOUT), D19.4 (DIN)
unnamed: J1.A5 (CC1), R6.1
unnamed: J1.B5 (CC2), R5.1

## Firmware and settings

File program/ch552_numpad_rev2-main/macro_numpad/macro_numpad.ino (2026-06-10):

/**
 * macro_numpad.ino main sketch of Numeric or Macro Keypad program using ch552g.
 * Copyright (c)  Takeshi Higasa, okiraku-camera.tokyo
 * * This software is released under the MIT License.
 * http://opensource.org/licenses/mit-license.php
 */

#include "USB_hid_composite.h"
#include "hid_keycode.h"
#include "ch552_watchdog.h"
#include "nvm_keymap.h" 
#include "hardware_config.h"  // for hardware dependent constants.

// ==========================================
// 1. ハードウェアピン配置・定数の定義
// ==========================================
#define ENCODER_PIN_A 14 // P1.4 (ロータリーエンコーダー A相)
#define ENCODER_PIN_B 15 // P1.5 (ロータリーエンコーダー B相)

const uint8_t cols[] = {16, 17, 32, 10};   // 4列
const uint8_t rows[] = {34, 33};            // 2行
const uint8_t row_masks[] = {0x10, 0x08};   // P3.4 と P3.3 のマスク値

// 初期レイアウト配列（8キー分）
const uint16_t text_scan_to_hid[8] = {
  HID_KEYPAD_1, HID_KEYPAD_2, HID_KEYPAD_3, HID_KEYPAD_4,
  HID_KEYPAD_5, HID_KEYPAD_6, HID_KEYPAD_7, HID_KEYPAD_8
};

// ==========================================
// 2. グローバル変数定義
// ==========================================
bool numeric_keypad = true;
int8_t current_layer = 0;       // 0:レイヤー0, 1:レイヤー1
unsigned long last_matrix_scan = 0;

// エンコーダー用変数（グレイコード状態遷移）
uint8_t old_AB = 3; 
int8_t enc_val = 0; 
const int8_t enc_states[] = {
    0, -1,  1,  0,
    1,  0,  0, -1,
   -1,  0,  0,  1,
    0,  1, -1,  0
};

// ==========================================
// 3. ロータリーエンコーダー 制御関数群
// ==========================================
void scan_encoder() {
    uint8_t A = digitalRead(ENCODER_PIN_A);
    uint8_t B = digitalRead(ENCODER_PIN_B);
    uint8_t AB = (A << 1) | B; 

    if (AB != old_AB) { 
        enc_val += enc_states[(old_AB << 2) | AB];
        old_AB = AB;

        // ALPS EC12は1クリックで4ステップ遷移する仕様
        if (enc_val >= 4) {
            // 右回り (下スクロール)
            send_key(FN_MS_WH_DOWN, 1);
            delay(2);
            send_key(FN_MS_WH_DOWN, 0);
            enc_val = 0;
        } else if (enc_val <= -4) {
            // 左回り (上スクロール)
            send_key(FN_MS_WH_UP, 1);
            delay(2);
            send_key(FN_MS_WH_UP, 0);
            enc_val = 0;
        }
    }
}

// ==========================================
// 4. USB・キースキャン・マクロイベント処理
// ==========================================
void write_code_callback(uint8_t sw, uint8_t layer, uint16_t code) {
  (void)layer; 
  if (sw == 0 && code == HID_KEYPAD_NUMLOCK)
    numeric_keypad = true;
  else if (sw == 0 && code != HID_KEYPAD_NUMLOCK)
    numeric_keypad = false;
}

void USBStartSuspend() {
}

uint8_t active_macro = 0; 
uint8_t macro_index = 0;  
int8_t macro_delay_count = 0; 

void key_event(uint8_t switch_num, uint8_t state) {
    if (switch_num < 1 || switch_num > NUM_KEYS )
        return;

    if (active_macro) {
        if (state) {
            macro_index = 0;
            macro_delay_count = 0;
            active_macro = 0;
            kbd_releaseAll();
        }
        return;
    } 

    uint16_t hidcode = read_nvm_code(switch_num - 1, current_layer);
    if (hidcode != 0) {
        uint8_t code = (uint8_t)hidcode & 0xff;
        uint8_t mod = (hidcode >> 8) & 0xff; 
        if ((code == HID_X_FN1) && state) { 
            current_layer ^= 1;
            return;
        }
        if (IS_MACRO_KEYCODE(code)) {
            if (state) {
                active_macro = hidcode - MACRO_KEYCODE_BASE;
                if (macro_ptrs[active_macro] == 0) {  
                    active_macro = 0;
                    return;
                }
                active_macro++;
                macro_index = 0;
                macro_delay_count = 0;
            }
        } else {
            if (mod && state) {
                send_modifiers(mod, 1);
                delay(20);
            }
            send_key(code, state);
            if (mod && !state) {
                delay(20);
                send_modifiers(mod, 0);
            }
        }
    }
}

#define scan_bytes 3
static uint8_t last_stable[scan_bytes];
static uint8_t last_scan[scan_bytes];

void scan() {
    __data uint8_t keys[scan_bytes] = {0}; 
    __data uint8_t key = 0;
    for(uint8_t row = 0; row < sizeof(rows); row++) {
        P3 &= ~row_masks[row];    
        delayMicroseconds(5);       

        uint8_t p1_val = ~P1;
        uint8_t p3_val = ~P3; 

        uint8_t col_bits = (((p1_val >> 6) & 1) << 0) |  
                           (((p1_val >> 7) & 1) << 1) |  
                           (((p3_val >> 2) & 1) << 2) |  // col3: P3.2
                           (((p1_val >> 0) & 1) << 3);   

        if (row & 1)
            keys[key++] |= (col_bits << 4); 
        else
            keys[key] = col_bits & 0x0f;    

        P3 |= row_masks[row];   
        delayMicroseconds(30);
    }
  
    uint8_t n = 0;
    for(uint8_t i = 0; i < sizeof(keys); i++) {
        if (last_scan[i] != keys[i])
            n++;
        last_scan[i] = keys[i];   
    }
    if (n)
        return; 

    for(key = 0; key < sizeof(keys); key++, n += 8) {
        uint8_t changes = keys[key] ^ last_stable[key];
        last_stable[key] = keys[key]; 
        if (changes) {
            uint8_t mask = 1;
            for (uint8_t i = 0; i < 8; i++, mask <<=1 )
                if (changes & mask) key_event(n + i + 1, keys[key] & mask ? 1 : 0);
        }
    }
}

void enter_bootloader_mode() {
#if defined(BOOT_LOAD_ADDR)
    USB_CTRL = 0;
    EA = 0;
    TMOD = 0;
    delay(10);
    __asm__("lcall #0x3800");
    for(;;) {}
#endif
}

void build_initial_layout() {
    for(int8_t i = 0; i < NUM_KEYS ; i++) { 
        uint16_t code = text_scan_to_hid[i];
        nvm_write_word(KEYMAP_START + (i << 1), code);        
        nvm_write_word(KEYMAP_START + NUM_KEYS * 2 + (i << 1), 0);  
    }
}

void type_macro_strings() {
    static uint8_t mod = 0;
    static uint8_t seg_start_index = 0xff; 

    if (macro_delay_count > 0) {
        macro_delay_count--;
        return ;
    }

    if (macro_index == 0)
        seg_start_index = 0xff;

    uint16_t macro_base = macro_ptrs[active_macro - 1];
    if (macro_base == 0) {  
        active_macro = 0;
        macro_delay_count = 0;
        seg_start_index = 0xff;
        return ;
    }
    uint8_t code = eeprom_read_byte(macro_base + macro_index);
    if (code == 0) {  
        active_macro = 0;
        macro_index = 0;
        macro_delay_count = 0;
        mod = 0;
        seg_start_index = 0xff;
        kbd_releaseAll();
        return ;
    }

    if (code == HID_M_SEGSTART) {
        if (seg_start_index == 0xff) {
            seg_start_index = macro_index;
        }
        macro_index++;
        return ;
    }

    if (code == HID_M_GOTO_SEG) {
        macro_index = (seg_start_index == 0xff) ? 0 : seg_start_index;
        return ;
    }

    if (IS_MACRO_DELAY_CODE(code)) {
        switch (code) {
        case HID_M_DELAY100:
            macro_delay_count = 10; 
            break;
        case HID_M_DELAY500:
            macro_delay_count = 50; 
            break;
        case HID_M_DELAY1000:
            macro_delay_count = 100;  
            break;
        default:
            macro_delay_count = 0;
        }
        macro_index++;
        return ;
    }

    if (IS_MODIFIER_KEYCODE(code)) { 
        mod |= (1 << ((code - HID_MODIFIERS) & 0x7)); 
        if ((mod & modifiers) & mod) {    
            send_modifiers(mod, false);
        } else {
            send_modifiers(mod, true);
        }
        delay(20);
    } else {
        send_key(code, 1);
        delay(10);
        send_key(code, 0);
    }
    macro_index++;
    return ;
}

// ==========================================
// 5. メイン設定（Setup）と メインループ（Loop）
// ==========================================
void setup() {
    // USB初期化
    usbhid_init();

    // ロータリーエンコーダーピン初期化と初期状態取得
    pinMode(ENCODER_PIN_A, INPUT_PULLUP);
    pinMode(ENCODER_PIN_B, INPUT_PULLUP);
    old_AB = (digitalRead(ENCODER_PIN_A) << 1) | digitalRead(ENCODER_PIN_B);

    // キースマトリクスピンの初期化
    for(uint8_t i = 0; i < sizeof(cols); i++)   
        pinMode(cols[i], INPUT_PULLUP);

    for(uint8_t i = 0; i < sizeof(rows); i++) {
        pinMode(rows[i], OUTPUT);
        digitalWrite(rows[i], 1);
    }

    // 内蔵EEPROM（キーマップ）初期化
    init_nvm_keymap();
    
    // 【追加部分】強制的に初期レイアウトをEEPROMに書き込んでリセットする
    // build_initial_layout();

    if (read_nvm_code(0, 0) != HID_KEYPAD_NUMLOCK)  
        numeric_keypad = false;

    // ウォッチドッグタイマー有効化
    wdt_enable(WDT_TIMEOUT);
}

void loop() {
    wdt_update();
  
    // マクロ文字列の自動送信処理
    if (active_macro)
        type_macro_strings();

    // 【最速】エンコーダー監視
    scan_encoder();

    // 【10ms周期】キースキャンマトリクス実行
    if (millis() - last_matrix_scan >= 10) {
        scan();
        last_matrix_scan = millis();
    }
}

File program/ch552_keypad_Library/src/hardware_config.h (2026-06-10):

// macro_numpad.ino main sketch of Numeric or Macro Keypad program using ch552g.
// Copyright (c)  Takeshi Higasa, okiraku-camera.tokyo
// This software is released under the MIT License.
// http://opensource.org/licenses/mit-license.php   

// Hardware dependent constants are defined in this file, such as the number of rows and columns, the eeprom memory map, etc. 
// These constants are used in multiple files, so they are defined in a separate header file.    

#ifndef HARDWARE_CONFIG_H
#define HARDWARE_CONFIG_H

// ★この1行を追加して、以下の設定を強制的に有効化します！
#define CH552_MACRO_NUMPAD 1

// EEPROM memory map

#define EEPROM_START    0   // start address of EEPROM
#define EEPROM_END      127  // end address of EEPROM. Do not write beyond this.

#ifdef BOARD_NAME_DEFINED
#undef BOARD_NAME_DEFINED
#endif


#ifdef CH552_MACRO_NUMPAD
#define BOARD_NAME_DEFINED 1
#define HID_RAW_ID 0x81

#define COLS 4     // ★ 5 から 4 に変更
#define ROWS 2     // ★ 4 から 2 に変更
#define NUM_KEYS (COLS * ROWS)
#define NUM_LAYERS 2

#define KEYMAP_START    2   // programable keymap starts at EEPROM_START. After EEPROM_KEYMAP_VALID1 and 2.
#define KEYMAP_SIZE     32  // (NUM_KEYS * NUM_LAYERS * 2) // size of keymap. 2bytes a key.    
#define MACRO_START	    82  // (KEYMAP_START + KEYMAP_SIZE) // macros start after keymap.
#define MACRO_SIZE	    45  // (MACRO_END - MACRO_START)  	  // size of macro storage in bytes.
#define MACRO_END       127 // (EEPROM_END)					  // end of macro storage. Do not write beyond this.
#define RE_COUNT 0	// No RE
#define RE_KEYMAP_START 128        // Start address of RE data. 
// RE data is stored in the order of CW(2bytes), CCW(2bytes) for each RE. 1 RE takes 4 bytes.
// RE that can be pressed is treated as a regular   key switch.  
#else
#ifdef CH552_MEDIAPAD
#define BOARD_NAME_DEFINED 1
#define HID_RAW_ID 0x82
#define COLS 2
#define ROWS 4
#define NUM_KEYS (COLS * ROWS)
#define NUM_LAYERS 2
#define RE_COUNT 1

#define KEYMAP_START	2   // programable keymap starts at EEPROM_START. After EEPROM_KEYMAP_VALID1 and 2.
#define KEYMAP_SIZE     32  // (NUM_KEYS * NUM_LAYERS * 2) // size of keymap. 2bytes a key.    
#define RE_KEYMAP_START 		34        // Start address of RE data. 
// RE that can be pressed is treated as a regular   key switch.  

#define RE_KEYMAP_END            (RE_KEYMAP_START + RE_COUNT * NUM_LAYERS * 4)	// end of RE data.

#define MACRO_START	    42  //  macros start after RE keymap.
#define MACRO_SIZE	    85  // (MACRO_END - MACRO_START)  	  // size of macro storage in bytes.
#define MACRO_END       127 // (EEPROM_END)					  // end of macro storage. Do not write beyond this.
#endif
#endif
#ifndef BOARD_NAME_DEFINED
#define HID_RAW_ID 0
#define COLS 4
#define ROWS 2
#define NUM_KEYS (COLS * ROWS)
#define NUM_LAYERS 1
#define RE_COUNT 0

#define KEYMAP_START	127   // programable keymap starts at EEPROM_START. After EEPROM_KEYMAP_VALID1 and 2.
#define KEYMAP_SIZE     0  // (NUM_KEYS * NUM_LAYERS * 2) // size of keymap. 2bytes a key.    
#define RE_KEYMAP_START 127       // Start address of RE data. 
// RE that can be pressed is treated as a regular   key switch.  

#define RE_KEYMAP_END            (RE_KEYMAP_START + RE_COUNT * NUM_LAYERS * 4)	// end of RE data.

#define MACRO_START	    42  //  macros start after RE keymap.
#define MACRO_SIZE	    85  // (MACRO_END - MACRO_START)  	  // size of macro storage in bytes.
#define MACRO_END       127 // (EEPROM_END)					  // end of macro storage. Do not write beyond this.
#endif

#endif  // HARDWARE_CONFIG_H

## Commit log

2026-05-13 回路図完成
    [macro-keyboard.kicad_pcb, macro-keyboard.kicad_sch]
2026-05-13 PCB作成
    [LED.kicad_sch, macro-keyboard.kicad_pcb, macro-keyboard.kicad_sch]
2026-05-14 PCB作成（続き）
    [LED.kicad_sch, macro-keyboard.kicad_pcb, macro-keyboard.kicad_sch]
2026-05-15 ケース設計
    [LED.kicad_sch, bom.csv, designators.csv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]
2026-05-18 ケース作成
2026-06-10 ソフトウェアを作成
    [macro-keyboard.kicad_sch]
2026-06-12 ホームページ作成
